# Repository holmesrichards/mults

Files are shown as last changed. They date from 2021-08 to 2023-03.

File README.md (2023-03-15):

# Multiples

This is a buffered multiple module in Kosmo format. It provides two buffered multiple circuits each with one input and four outputs; the input to the second is normalized to the input of the first, so it can function as a 1-in, 8-out multiple.

It is intended to be V/oct-safe. Voltage follower stages are used to guarantee unity gain. Input impedance is 1M instead of the common 100k, resulting in attenuation (of a signal from a source with 1k output impedance) by 0.1% rather than 1% — corresponding to 1.2 cents per octave instead of 12. Output current limiting resistors are in the loop, so there will be no attenuation at the downstream input.

Two things to watch out for:

* There are no stabilization capacitors in the design. With the in-the-loop resistor, the potential exists for op amp instability when driving a capacitive load. In practice this probably means don't use 20 meter long patch cords on the outputs. In more normal usage there is not likely to be a problem.
* Use of JFET op amps (TL074) in voltage followers rather than paired inverting stages means there can be phase reversal if the input signal is less than 4 V from the negative rail, giving incorrect outputs. If your inputs might go more negative than -8 V, use a different multiple. There also is no protection against overvoltage outside the ±12 V range, so exercise care not to connect anything that might give such large voltages.

## Current draw
16 mA +12 V, 16 mA -12 V

## Photos

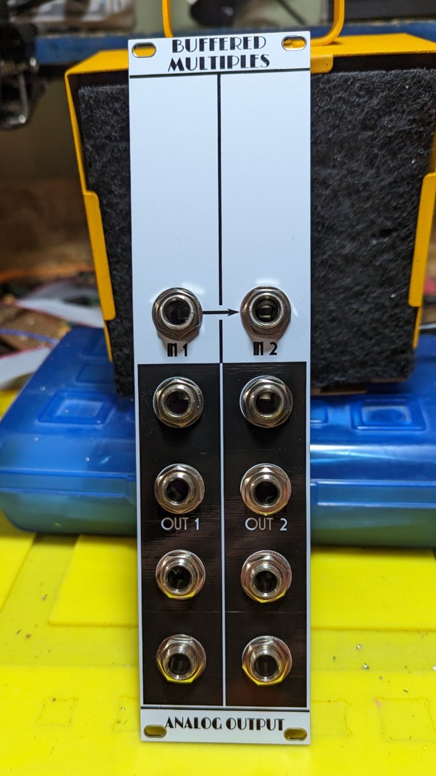
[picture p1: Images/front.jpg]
front


## Documentation

* [Schematic](Docs/multiples_schematic.pdf)
* PCB layout: [front](Docs/2D/multiples/multiples_front.svg), [back](Docs/2D/multiples/multiples_back.svg)
* [BOM](Docs/BOM/multiples_bom.md)
* [How it works](Docs/howitworks.md)
* [Blog post](https://analogoutputblog.wordpress.com/2023/03/13/buffered-multiples-again/)

## GitHub repository

* [https://github.com/holmesrichards/mults](https://github.com/holmesrichards/mults)

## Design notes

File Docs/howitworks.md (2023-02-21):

# Multiples: How it works

This is a very simple circuit: Basically each input is fanned out to four voltage followers. On each input there is a 1M resistor to ground to establish the input impedance and on each output there is a 1k current limiting resistor inside the op amp loop.

Using a 1M input impedance instead of the more usual 100k means the voltage attenuation for an upstream module with 1k output impedance will be 1k/1001k = 0.1% instead of 1k/101k = 1%. The former is generally acceptable for a 1 V/oct control voltage while the latter is 1/8 of a semitone per octave out of tune.

Using in-the-loop current limiting resistors means the output impedance is zero rather than the 1k it would be with out-of-the-loop resistors. The latter into a downstream module with 100k input impedance would again attenuate the voltage by an unacceptable 1%.

Using voltage followers gives four outputs per input with one quad op amp and five resistors, and guarantees unity gain; a design based on pairs of inverting amplifiers gives only three outputs per input with one quad op amp and 11 resistors, and will give unity gain (±0.1%) only if (expensive) precision resistors are used, or if resistors are hand matched at the 0.1% level, or if some of the resistors are trim pots and the module is calibrated carefully. The small number of needed components for a voltage follower design means all ten jacks and all through hole components for a dual 4-output buffer module will fit on a single PCB behind a 50 mm wide Kosmo format panel; parts for an inverter based design probably would not, unless using surface mount components.

However, there are drawbacks to this design.

The in-the-loop current limiting resistors do nothing, on their own, to suppress op amp instabilities due to capacitive loads; out-of-the-loop resistors would. With in-the-loop resistors, suppressing instability requires adding capacitors in the loop, whose optimal value would depend on the capacitive load. However, such instability is unlikely to be a problem unless very long patch cables are used on the outputs, so these capacitors have been omitted due to space constraints.

The other option would be to use smaller value, e.g. 100Ω, out-of-the-loop resistors, but if the output were shorted to ±12 V, the current would try to go to 12 V / 100Ω = 120 mA. The TL074 would not be able to source or sink that much current, but supposing it were 80 mA, the power dissipated by the resistor would be (80 mA)<sup>2</sup> x 100Ω = 0.64 W, likely to burn up the 1/4 W resistors normally used — and 1 W resistors would take up more space than is available. With 1k resistors the current is only 12 mA and the power dissipated is 0.14 W, which 1/4 W resistors can handle.

The non inverting voltage follower design exposes the op amp input pins to the input voltages, unlike an inverting amp design where the input pins are at zero volts. This has at least two negative consequences. First, the op amps could be damaged if the input voltages are more than a diode drop outside the ±12 V range. Second, the TL074 is susceptible to phase reversal when the input is below -8 V. If phase reversal occurs, the voltage follower output becomes about +12 V instead of the expected -8 V or lower. 

I have decided these potential problems are an acceptable price to pay for the advantages of the design. In my setup, it is very unlikely the input voltage would ever be outside the ±12 V range — there are no larger DC voltage sources in the synth. As for phase reversal, while voltages below -8 V are certainly possible, they are exceptional; usually all signals in my synth are between -5 V and +10 V. On the rare occasion where I might really need to buffer a signal that could go below -8 V I have another, inverting amp based buffered multiple I can use.

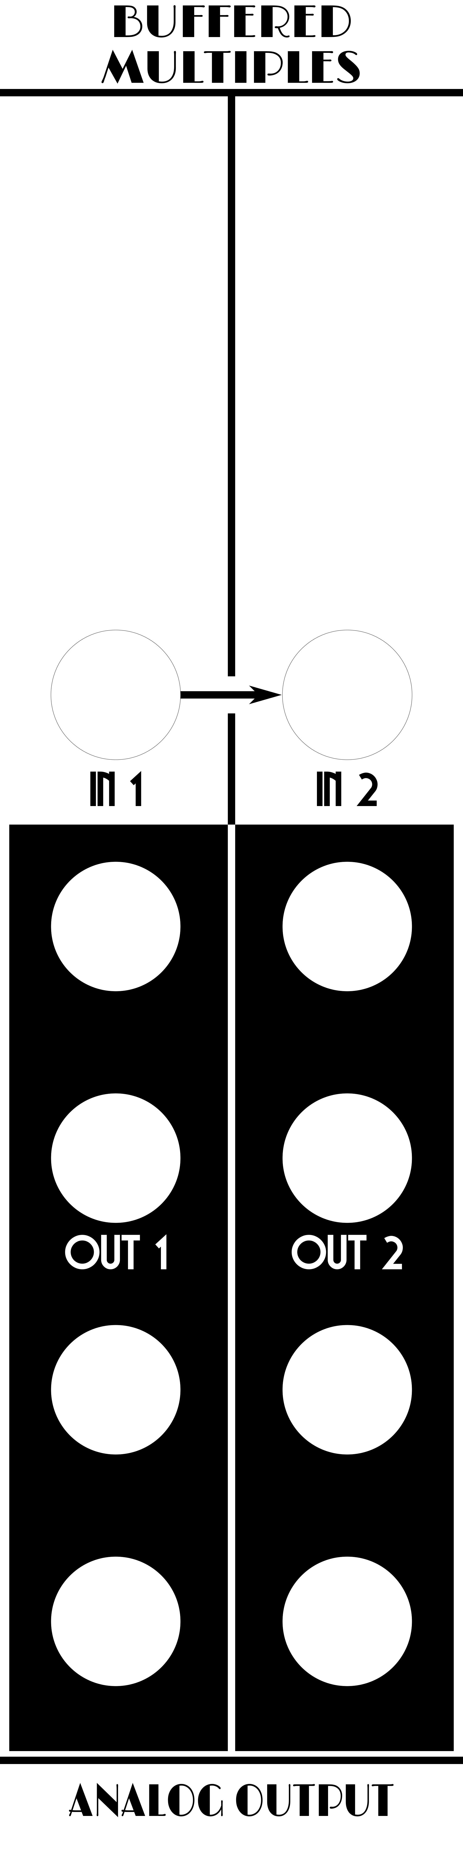
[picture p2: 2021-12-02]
Images/multiples_panel_art.png

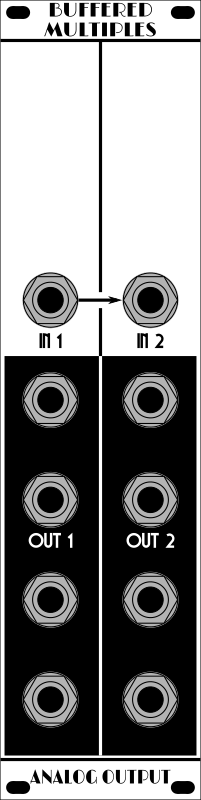
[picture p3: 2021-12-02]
Images/multiples_panel.png

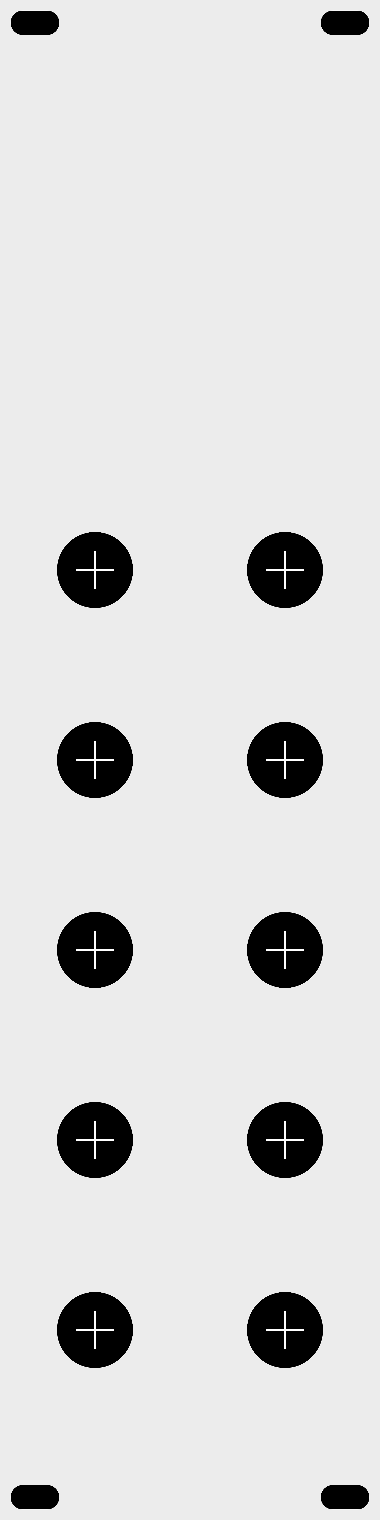
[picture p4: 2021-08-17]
Images/multiples_panel_holes.png

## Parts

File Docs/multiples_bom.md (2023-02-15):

# multiples.kicad_sch BOM

Tue 14 Feb 2023 09:01:43 PM EST

Generated from schematic by Eeschema 7.99.0-unknown-2cc3d8e9bc~165~ubuntu22.04.1

**Component Count:** 33

| Refs | Qty | Component | Description | Vendor | SKU |
| ----- | --- | ---- | --- | ---- | ---- |
| C1, C2 | 2 | 10uF | Electrolytic capacitor, 2.5 mm pitch | Tayda | A-4349 |
| C3, C4, C5, C6 | 4 | 100nF | Ceramic disc capacitor, 5 mm pitch | Tayda | A-553 |
| D1, D2 | 2 | 1N5817 | Schottky diode | Tayda | A-159 |
| J1 | 1 | Synth_power_2x5 | Pin header 2.54 mm 2x5 | Tayda | A-2939 |
| J2, J3, J4, J5, J6, J8, J9, J10, J11 | 9 | AudioJack2 | Audio Jack, 2 Poles (Mono / TS) | Tayda | A-1121 |
| J7 | 1 | AudioJack2_SwitchT | Audio Jack, 2 Poles (Mono / TS), Switched T Pole (Normalling) | Tayda | A-1121 |
| J12, J13 | 2 | DIP-14 | 14 pin DIP socket |  |  |
| R1, R6 | 2 | 1M | Resistor |  |  |
| R2, R3, R4, R5, R7, R8, R9, R10 | 8 | 1k | Resistor |  |  |
| U1, U2 | 2 | TL074 | Quad operational amplifier, DIP-14 | Tayda | A-1138 |

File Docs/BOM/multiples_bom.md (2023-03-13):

# multiples.kicad_sch BOM

Mon 13 Mar 2023 01:02:44 PM EDT

Generated from schematic by Eeschema 7.0.1-3b83917a11~171~ubuntu22.04.1

**Component Count:** 33

| Refs | Qty | Component | Description | Vendor | SKU |
| ----- | --- | ---- | --- | ---- | ---- |
| C1, C2 | 2 | 10uF | Electrolytic capacitor, 2.5 mm pitch | Tayda | A-4349 |
| C3–6 | 4 | 100nF | Ceramic disc capacitor, 5 mm pitch | Tayda | A-553 |
| D1, D2 | 2 | 1N5817 | Schottky diode | Tayda | A-159 |
| J1 | 1 | Synth_power_2x5 | Pin header 2.54 mm 2x5 | Tayda | A-2939 |
| J2–6, J8–11 | 9 | AudioJack2 | Audio Jack, 2 Poles (Mono / TS) | Tayda | A-1121 |
| J7 | 1 | AudioJack2_SwitchT | Audio Jack, 2 Poles (Mono / TS), Switched T Pole (Normalling) | Tayda | A-1121 |
| J12, J13 | 2 | DIP-14 | 14 pin DIP socket | Tayda | A-004 |
| R1, R6 | 2 | 1M | Resistor |  |  |
| R2–5, R7–10 | 8 | 1k | Resistor |  |  |
| U1, U2 | 2 | TL074 | Quad operational amplifier, DIP-14 | Tayda | A-1138 |

## Resistors in color band order
|Value|Qty|Refs|
|----|----|----|
|1k|8|R2–5, R7–10|
|1M|2|R1, R6|

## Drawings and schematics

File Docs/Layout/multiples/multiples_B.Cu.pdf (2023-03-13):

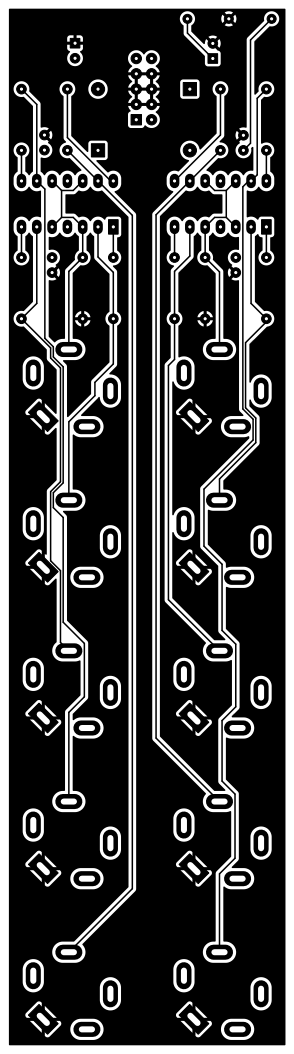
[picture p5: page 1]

Id: 1/1 Title: File: multiples.kicad_pcb Sheet:

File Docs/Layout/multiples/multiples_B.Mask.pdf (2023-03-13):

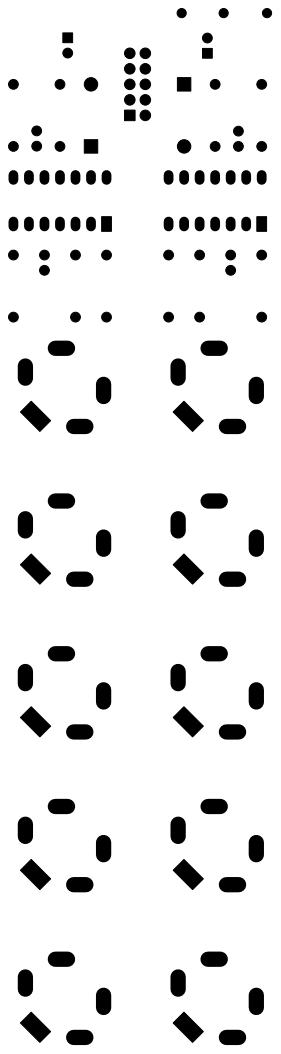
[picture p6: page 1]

Id: 1/1 Title: File: multiples.kicad_pcb Sheet:

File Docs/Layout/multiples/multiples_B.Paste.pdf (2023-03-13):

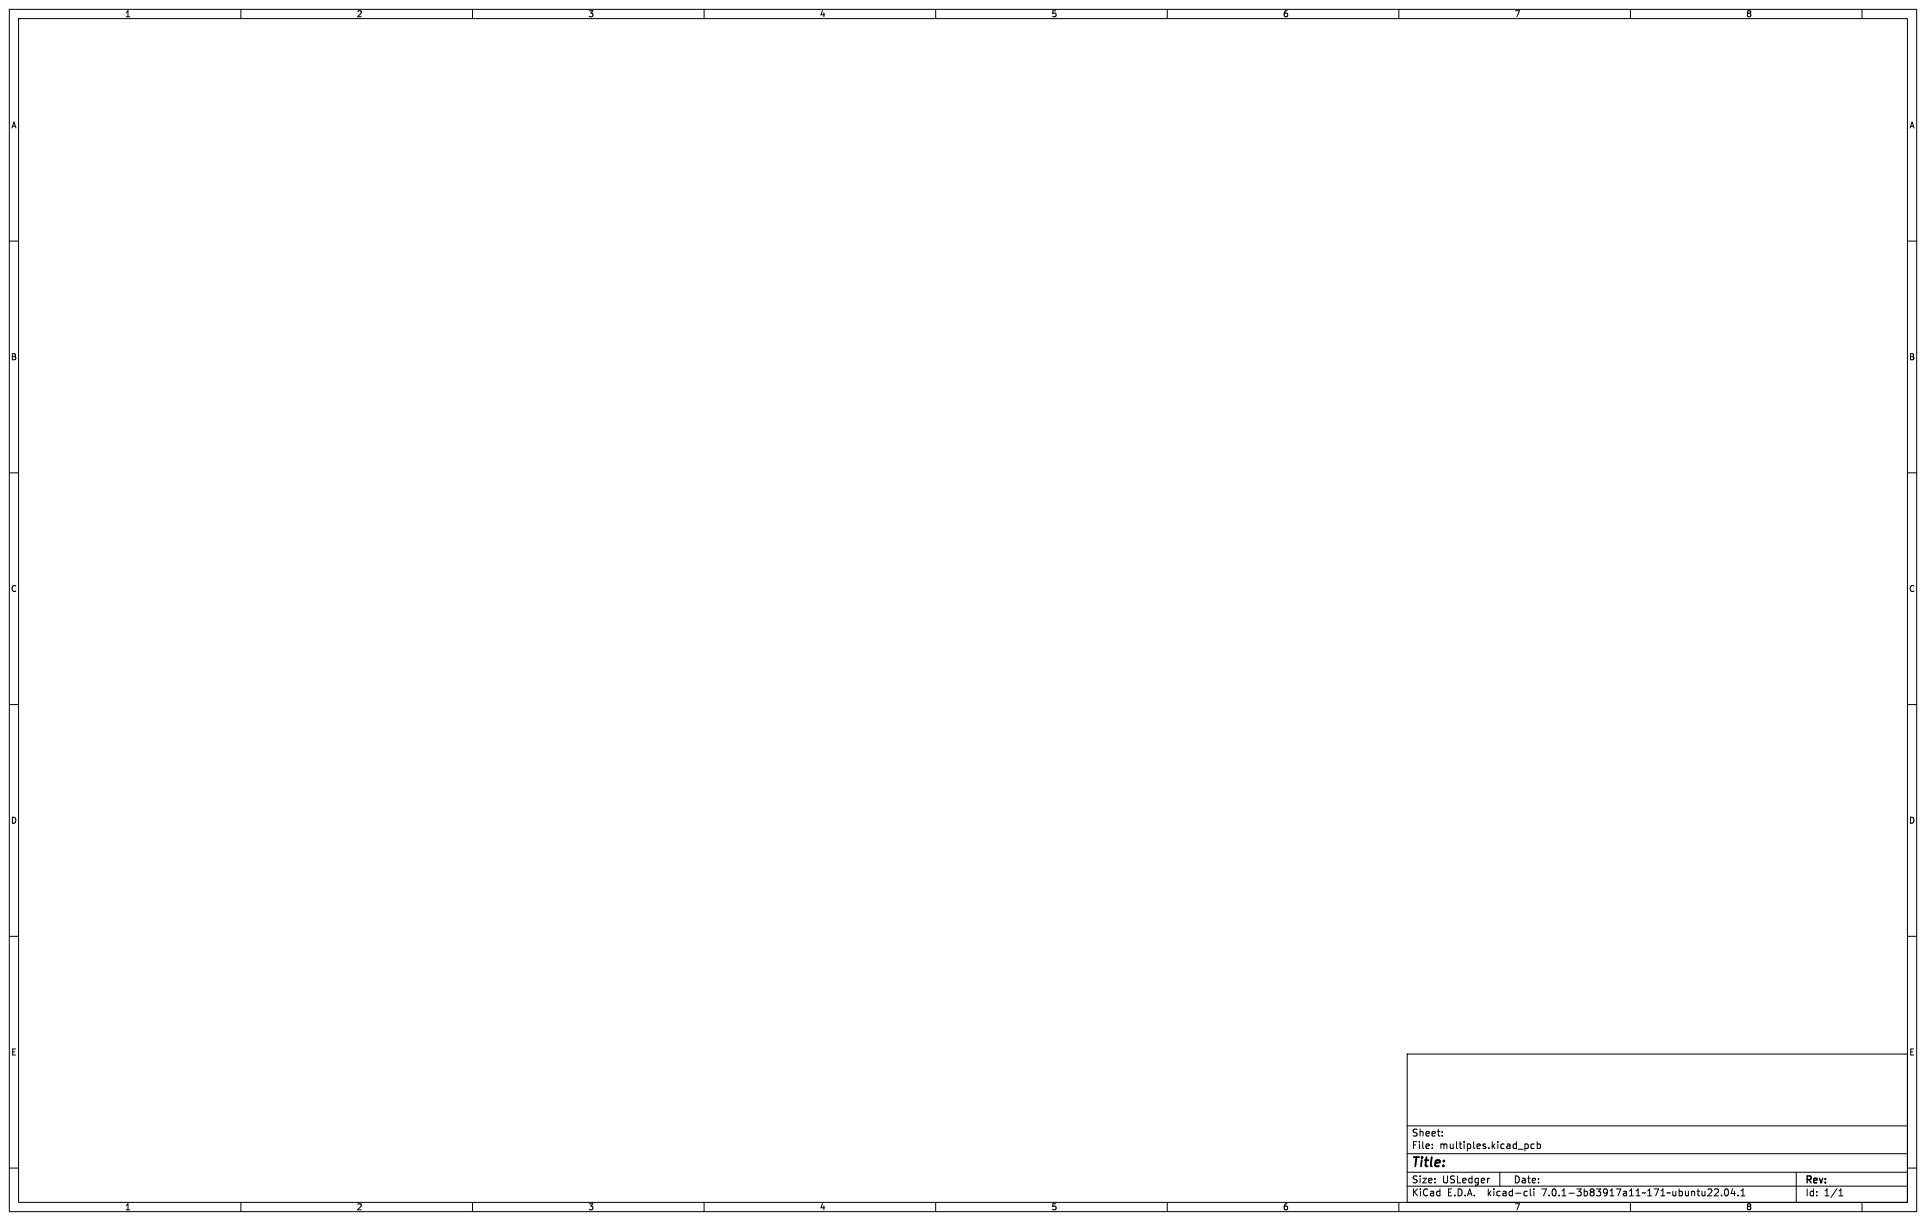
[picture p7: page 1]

Id: 1/1 Title: File: multiples.kicad_pcb Sheet:

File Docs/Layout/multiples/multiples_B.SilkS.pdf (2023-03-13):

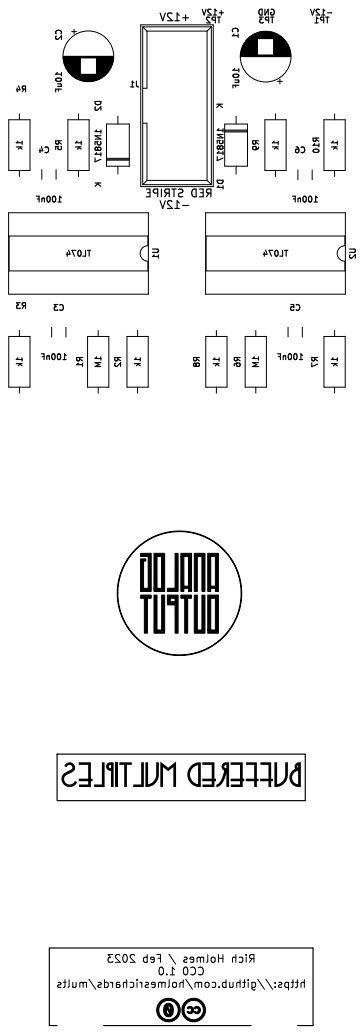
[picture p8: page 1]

https://github.com/holmesrichards/mults BufferedMultiples

Id: 1/1 Title: File: multiples.kicad_pcb Sheet:

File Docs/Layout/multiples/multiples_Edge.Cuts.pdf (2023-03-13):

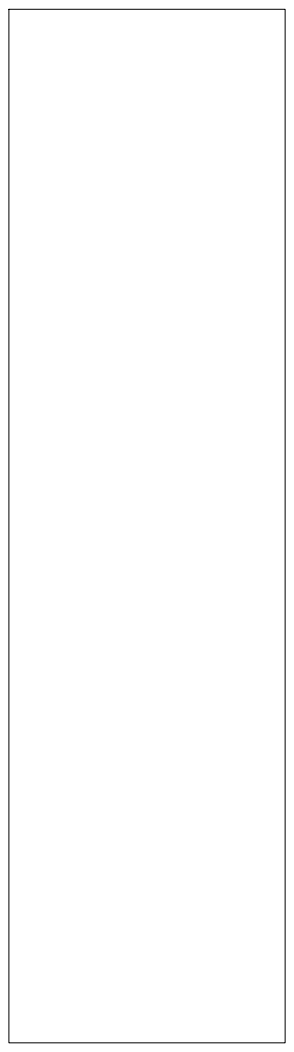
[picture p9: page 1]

Id: 1/1 Title: File: multiples.kicad_pcb Sheet:

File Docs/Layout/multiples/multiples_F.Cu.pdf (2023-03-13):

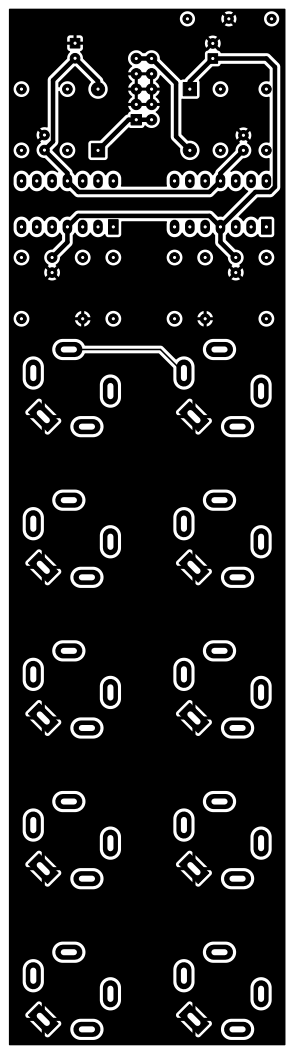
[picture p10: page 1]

Id: 1/1 Title: File: multiples.kicad_pcb Sheet:

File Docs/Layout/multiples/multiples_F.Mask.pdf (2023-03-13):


Id: 1/1 Title: File: multiples.kicad_pcb Sheet:

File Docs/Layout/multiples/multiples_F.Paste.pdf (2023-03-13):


Id: 1/1 Title: File: multiples.kicad_pcb Sheet:

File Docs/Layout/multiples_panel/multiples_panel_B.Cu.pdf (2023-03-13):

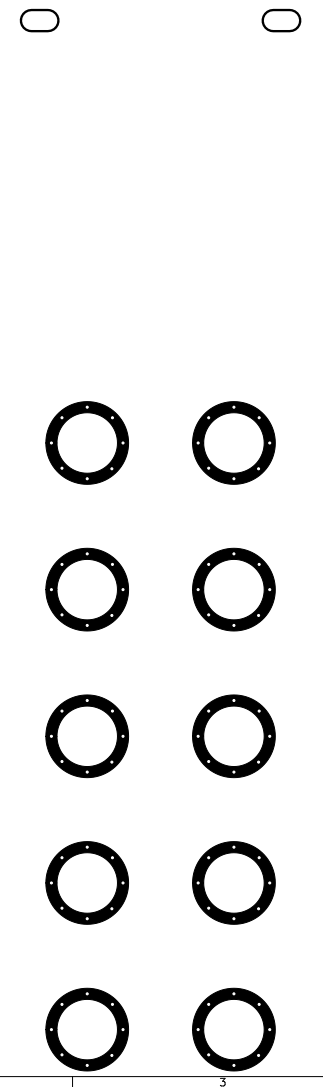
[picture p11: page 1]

Id: 1/1 Title: File: multiples_panel.kicad_pcb Sheet:

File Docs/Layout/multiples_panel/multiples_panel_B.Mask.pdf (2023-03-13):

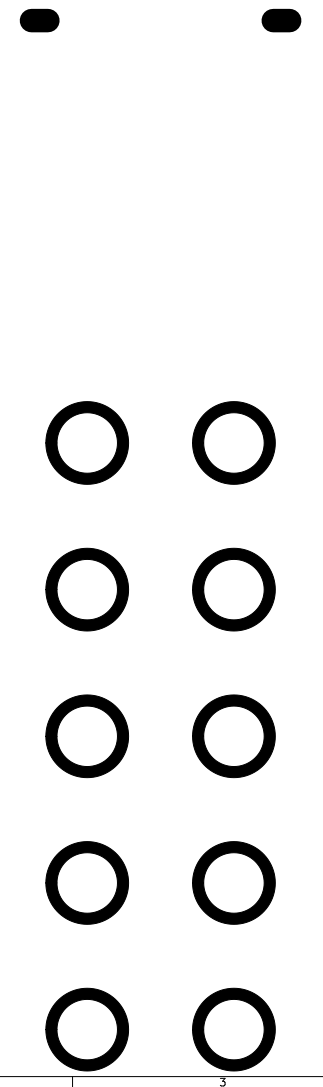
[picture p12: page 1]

Id: 1/1 Title: File: multiples_panel.kicad_pcb Sheet:

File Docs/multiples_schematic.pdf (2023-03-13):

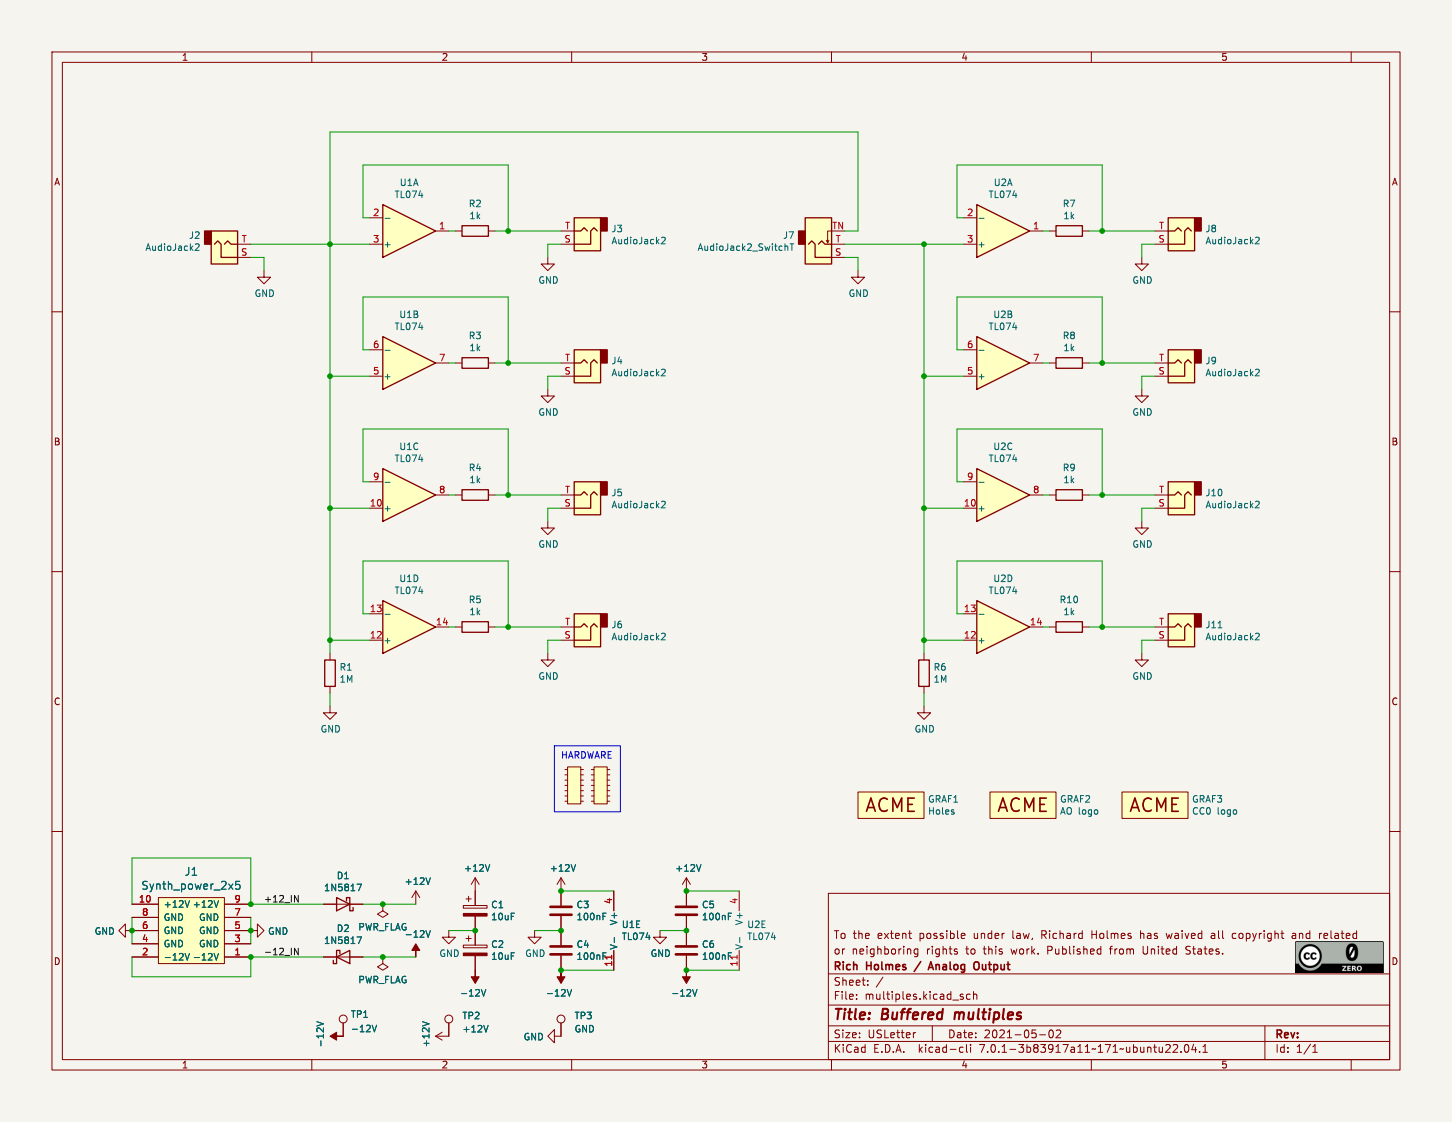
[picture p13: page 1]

Id: 1/1 Title: Buffered multiples

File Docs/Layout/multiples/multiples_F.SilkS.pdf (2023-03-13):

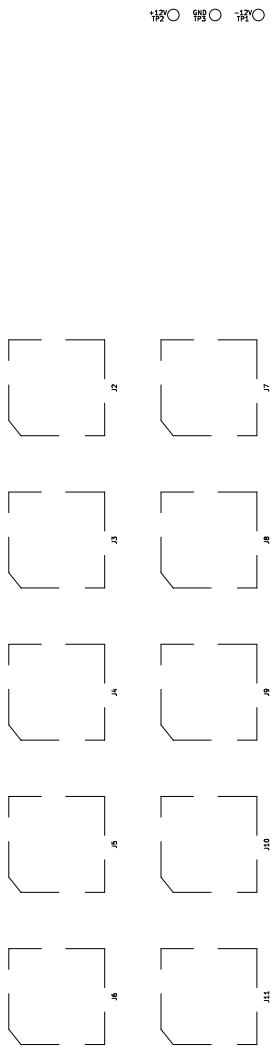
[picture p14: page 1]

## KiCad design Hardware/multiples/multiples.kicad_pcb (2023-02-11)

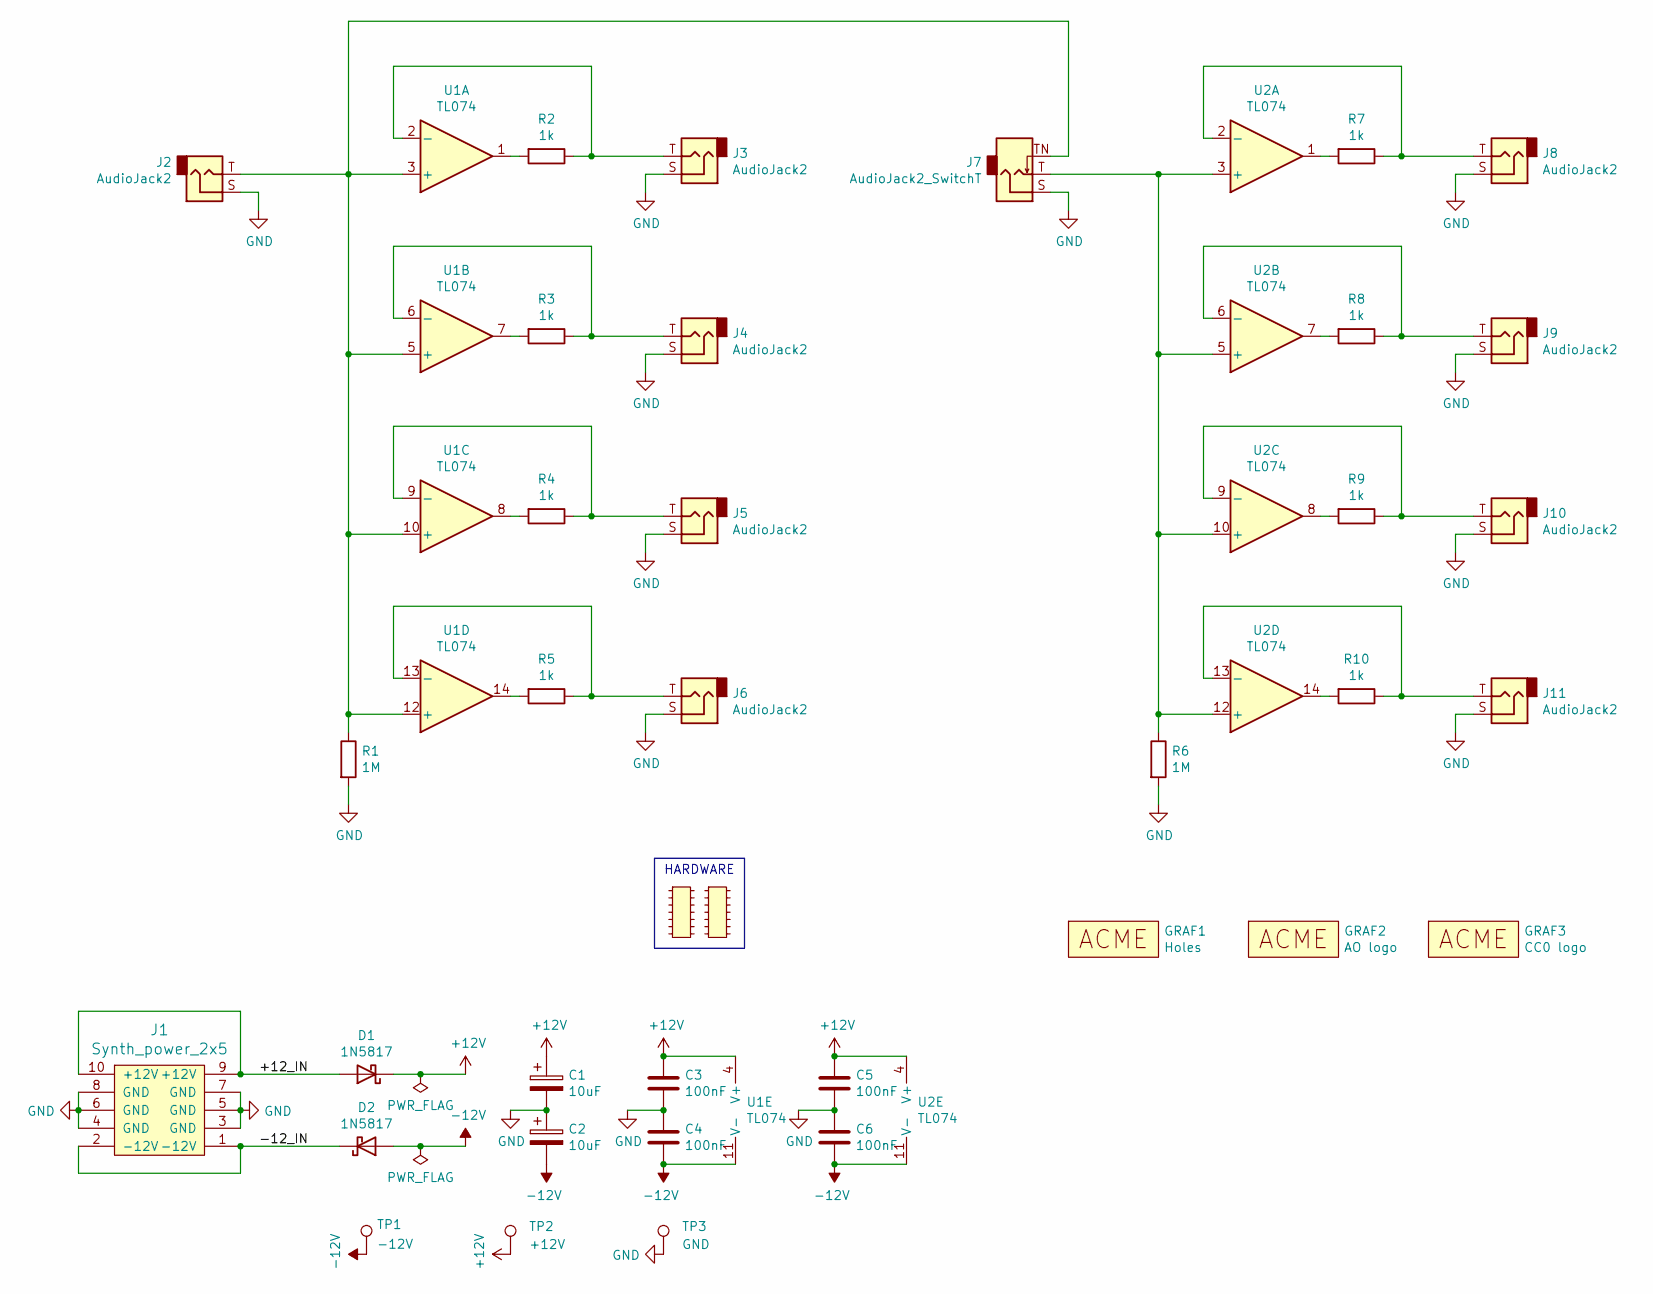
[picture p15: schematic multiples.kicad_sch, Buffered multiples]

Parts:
C1, C2: 10uF; CP_Radial_D6.3mm_P2.50mm
C3, C4, C5, C6: 100nF; C_Disc_D3.0mm_W1.6mm_P2.50mm
D1, D2: 1N5817; D_DO-41_SOD81_P10.16mm_Horizontal
GRAF1: Holes; multiples_panel_holes
GRAF2: AO logo; analogoutput
GRAF3: CC0 logo; CC0_logo
J1: Synth_power_2x5; Power_Header
J2, J3, J4, J5, J6, J8, J9, J10, J11: AudioJack2; Jack_6.35mm_PJ_629HAN_slots
J7: AudioJack2_SwitchT; Jack_6.35mm_PJ_629HAN_slots
J12, J13: DIP-14
R1, R6: 1M; R_Axial_DIN0207_L6.3mm_D2.5mm_P10.16mm_Horizontal
R2, R3, R4, R5, R7, R8, R9, R10: 1k; R_Axial_DIN0207_L6.3mm_D2.5mm_P10.16mm_Horizontal
TP1: -12V; TestPoint_THTPad_D1.5mm_Drill0.7mm
TP2: +12V; TestPoint_THTPad_D1.5mm_Drill0.7mm
TP3: GND; TestPoint_THTPad_D1.5mm_Drill0.7mm
U1, U2: TL074; DIP-14_W7.62mm_Socket_LongPads

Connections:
+12V: C1.1, C3.1, C5.1, D1.1 (K), TP2.1, U1.4 (V+), U2.4 (V+)
-12V: C2.2, C4.2, C6.2, D2.2 (A), TP1.1, U1.11 (V-), U2.11 (V-)
/+12_IN: D1.2 (A), J1.9 (+12V), J1.10 (+12V)
/-12_IN: D2.1 (K), J1.1 (-12V), J1.2 (-12V)
GND: C1.2, C2.1, C3.2, C4.1, C5.2, C6.1, J1.3 (GND), J1.4 (GND), J1.5 (GND), J1.6 (GND), J1.7 (GND), J1.8 (GND), J2.S, J3.S, J4.S, J5.S, J6.S, J7.S, J8.S, J9.S, J10.S, J11.S, R1.2, R6.2, TP3.1
unnamed: R2.2, U1.1
unnamed: R3.2, U1.7
unnamed: R4.2, U1.8
unnamed: R5.2, U1.14
unnamed: R7.2, U2.1
unnamed: R8.2, U2.7
unnamed: R9.2, U2.8
unnamed: R10.2, U2.14
unnamed: J2.T, J7.TN, R1.1, U1.3 (+), U1.5 (+), U1.10 (+), U1.12 (+)
unnamed: J3.T, R2.1, U1.2 (-)
unnamed: J4.T, R3.1, U1.6 (-)
unnamed: J5.T, R4.1, U1.9 (-)
unnamed: J6.T, R5.1, U1.13 (-)
unnamed: J7.T, R6.1, U2.3 (+), U2.5 (+), U2.10 (+), U2.12 (+)
unnamed: J8.T, R7.1, U2.2 (-)
unnamed: J9.T, R8.1, U2.6 (-)
unnamed: J10.T, R9.1, U2.9 (-)
unnamed: J11.T, R10.1, U2.13 (-)

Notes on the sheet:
HARDWARE

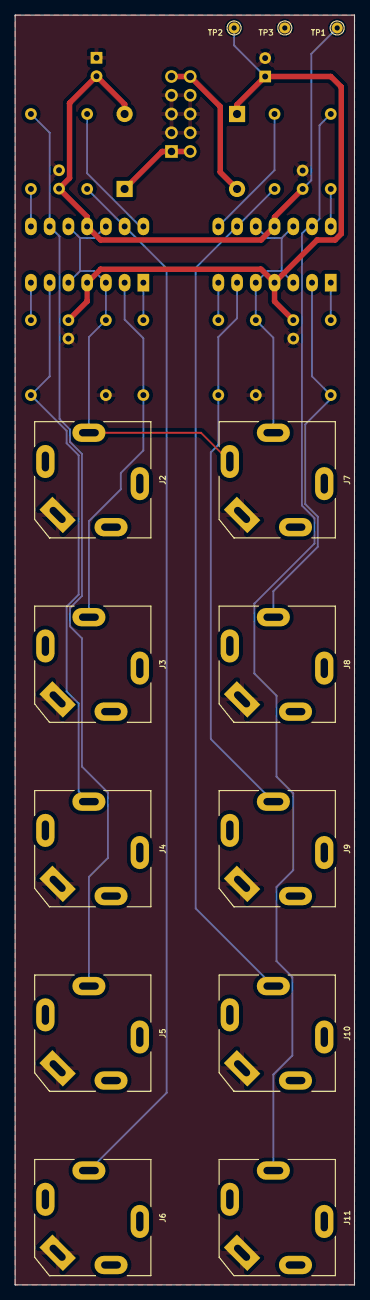
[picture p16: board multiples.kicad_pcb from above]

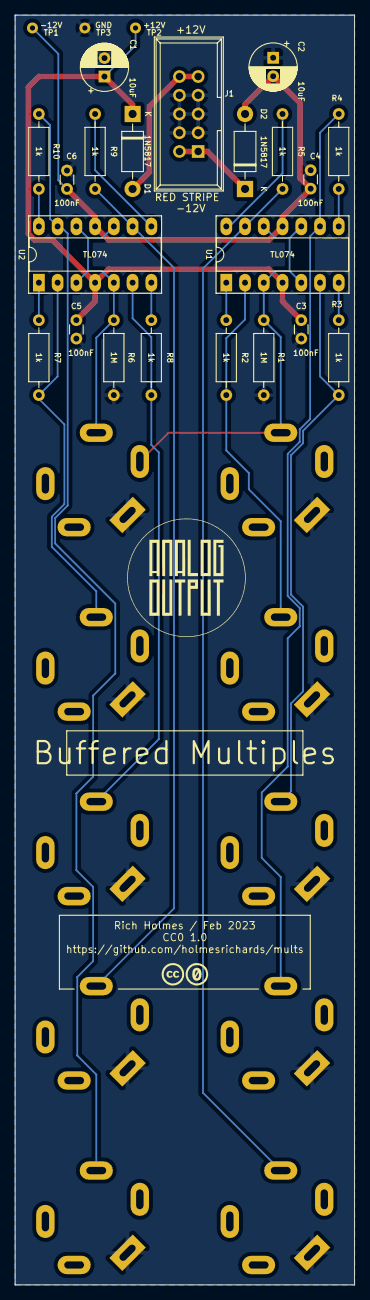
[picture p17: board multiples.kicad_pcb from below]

Board: 2 copper layers, 46.0 x 172.1 mm, 37 parts (23 on the bottom side), 23 nets.

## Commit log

2021-05-02 Initial version
    [multiples.kicad_pcb, multiples.sch]
2021-07-29 Footprints, ground tip normal
    [multiples.sch]
2021-08-17 PCB layout
    [multiples.kicad_pcb, multiples.sch]
2021-08-20 Submodules; panel
    [multiples_panel.kicad_pcb, multiples_panel.sch]
2021-08-20 No NPTH specialization
    [multiples_panel.kicad_pcb, multiples_panel.sch]
2021-09-09 Clean up libraries, Schottky footprint update
    [multiples.kicad_pcb, multiples.sch]
2021-12-02 Panel art tweak
    [multiples_panel.kicad_pcb]
2022-02-01 Better .gitignore
    [multiples.kicad_pcb, multiples.kicad_sch]
2023-02-05 KiCad 7, libraries to folder
    [multiples.kicad_pcb, multiples.kicad_sch, multiples.sch]
2023-02-11 Pre fab tweaks
    [multiples.kicad_pcb, multiples.kicad_sch]
2023-02-11 Pre fab tweaks, Gerbers
    [multiples-CmtUser.gbr, multiples-CuBottom.gbl, multiples-CuTop.gtl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]
2023-02-15 DIP sockets; PDF docs; README
    [multiples.kicad_sch]
2023-03-15 Add current draw
